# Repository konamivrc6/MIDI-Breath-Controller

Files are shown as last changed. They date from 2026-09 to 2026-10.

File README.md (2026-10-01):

# LnWS Breath Controller

吹气式 MIDI 呼吸控制器。MPX5010DP 气压传感器 + Pro Micro，把吹气压力映射成 MIDI CC#2 发给宿主。

- 开机自动零点校准
- 两种力度曲线（线性 / 平方根），由拨动开关切换
- TM1637 四位数码管实时显示当前 CC 值
- 主循环全程非阻塞

## 硬件

| 部件 | 型号 | 备注 |
|---|---|---|
| 主控 | Pro Micro (ATmega32U4, 5V / 16 MHz) | 2×12 排针插座 |
| 压力传感器 | MPX5010DP | 6 脚单排 SIP，量程 10 kPa |
| 显示 | TM1637 四位数码管 | 4 脚，2.54mm 间距 |
| 开关 | 3 脚拨动开关 | 2.0mm 间距 |
| 消抖电容 | 3 × 1µF 0805 MLCC | 并联，接开关公共端与 GND 之间 |
| 上拉 | 4.7k 0805 | 开关输入，保证触点湿电流 |
| 去耦电容 | 直插 1 枚 | 传感器旁电源去耦 |
| 气管 | 硅胶软管 | 内径 4mm / 外径 6mm |

PCB 尺寸 60 × 50 mm 双面板，4 个 3.2mm 安装孔。
设计文件 `PCB/LnWS Breath Controller.eprj2`（EasyEDA Pro），现行 Gerber 为 **`2026-10-01`**。

该版相对 06-07 首版的主要变化：布线由纯走线改为大面积铺铜；开关消抖电容由直插 100nF 换成 3 颗并联的 1µF 0805 MLCC；新增 4.7k 湿电流上拉。

### 引脚对照表

下表由 Gerber 铜箔层走线逆向得出，与固件里的定义一致。

| 信号 | Pro Micro 引脚 | 说明 |
|---|---|---|
| 传感器 Vout | **A0**（18 / PF7） | 模拟输入 |
| 传感器 GND | GND | |
| 传感器 Vs | VCC（5V） | |
| 数码管 CLK | **2** | |
| 数码管 DIO | **3** | |
| 拨动开关 | **4** | 接开关公共端；另一侧接地，靠 `INPUT_PULLUP` |
| 数码管 VCC | VCC（5V） | |
| 数码管 GND | GND | |

### 开关消抖的设计依据

开关公共端接 **4.7k 上拉**，并 **3 颗 1µF 0805 MLCC 并联到 GND**，构成 RC 消抖。固件里**不做软件消抖**，全部靠这段硬件完成。

两个参数都是被约束推出来的，**不要随手改其中一个**：

**上拉为什么是 4.7k —— 湿电流（wetting current）。**
机械开关的触点会形成氧化膜，电流太小就击不穿，接触电阻变得不稳定。镍/银镀层要求 **≥1mA**。触点闭合时电流 = 5V / R，所以 **R ≤ 5k**。取 4.7k → 1.06mA，是在满足湿电流的前提下能取的最大阻值。
（注意：Pro Micro 内部上拉是 20~50k，也就是 0.1~0.25mA —— 经典「内部上拉 + 100nF」的做法本来就跑在湿电流以下。）

**电容为什么是 3 颗 —— DC bias。**
MLCC 在直流偏压下容值会衰减，且衰减按**每颗**计算，并联不会改善比例。X7R 0805 在 5V 偏压下的典型衰减：25V 耐压约 25%，16V 约 35~45%，X5R 更差。所以不能按标称值算，要按**有效值**算：

| 规格 | 颗数 | 标称 | 有效值 | τ = R_total × C_eff |
|---|---|---|---|---|
| 1µF 0805 25V X7R | 2 | 2.0 µF | 1.5 µF | 5.7 ~ 6.4 ms |
| 1µF 0805 16V X7R | 3 | 3.0 µF | 1.65 ~ 1.95 µF | 6.9 ~ 7.7 ms |
| 1µF 0805 16V X5R | 3 | 3.0 µF | 1.35 ~ 1.65 µF | 5.7 ~ 6.4 ms |

本板用 3 颗，对上述任一规格都留有余量（小型滑动开关典型抖动 1~5ms）。反过来，只放 1 颗在衰减超过 30% 时 τ 就会掉到 3ms 以下，压不住抖动。

**并联上拉的影响 —— 反而让 τ 变确定了。**
固件保留 `INPUT_PULLUP`，内部上拉（20~50 kΩ）与外部 4.7k 并联，总阻为 **3.81 ~ 4.30 kΩ**：

| R_pu | R_total | 湿电流 |
|---|---|---|
| 20 kΩ | 3.81 kΩ | 1.31 mA |
| 30 kΩ | 4.06 kΩ | 1.23 mA |
| 50 kΩ | 4.30 kΩ | 1.16 mA |

因为 4.7k 远小于内部上拉，**它主导了并联结果** —— 内部那个 2.5 倍的离散被压缩到 1.13 倍，τ 实际上是确定的。副带好处是湿电流从 1.06mA 抬到 1.16~1.31mA。
保留内部上拉还有兜底作用：万一外部 4.7k 虚焊，τ 会变长到 30~75ms，模式切换变迟钝但功能不丢。

> ⚠️ 改动这里的 R 或 C 之前，务必重算**湿电流**和 **DC bias 后的有效容值** —— 这两者是互相拉扯的（湿电流要求 R 小，消抖要求 R×C 大），只调一个必然破坏另一个。

### MPX5010DP 接线

| 脚 | 名称 | 板上接到 |
|---|---|---|
| 1 | Vout | A0 |
| 2 | GND | GND |
| 3 | Vs | 5V |
| 4 | V1 | 悬空 |
| 5 | V2 | 悬空 |
| 6 | VEX | 悬空 |

> ✅ **4 / 5 / 6 脚全部悬空，符合数据手册。** V1、V2、VEX 是工厂激光修调脚，NXP 明确要求悬空不接。
> 早期版本曾把 4 脚接到 5V、5 脚接到 GND（偏离数据手册），现行版本已修正。

> ⚠️ **不要直接焊接传感器。** 引脚粗、散热快，烙铁停留稍久就会烫坏——本项目已经因此报废过一块。建议在板上装 **6 脚圆孔母座**，传感器插上去，既不烫坏也方便更换。

> ⚠️ **1 脚是缺口标记的那一端。** 插反会把 Vout 直接接到 5V 上。

## 开发环境

### 1. 安装依赖库

把 `libraries/` 下的 **`MIDIUSB`** 和 **`TM1637`** 拷贝到：

```
%USERPROFILE%\Documents\Arduino\libraries\
```

### 2. 安装开发板定义

这个板子定义不在官方 Arduino AVR 核里，需要手动追加。

把 `boards_add in the end.txt` 的内容**追加到文件末尾**：

```
%LOCALAPPDATA%\Arduino15\packages\arduino\hardware\avr\<版本>\boards.txt
```

追加后重启 Arduino IDE，开发板菜单里会出现 **"LnWS Breath Controller"**。

> ⚠️ **Arduino AVR 核一升级，这个文件就会被重置**，需要重新追加。

定义本身只是「SparkFun Pro Micro 换了个 USB 设备名」，其中有两处是踩过坑才改对的：

- **`build.variant=leonardo`** —— 官方核里没有 `promicro` variant。Leonardo 与 Pro Micro 的引脚映射逐位相同（已核对两张 `PROGMEM` 表的 `digital_pin_to_port_PGM` / `digital_pin_to_bit_mask_PGM`），所以直接复用。
- **`upload.tool.serial` / `upload.tool.default=avrdude`** —— 这两行原本没有，IDE 2.x 上传时会报 `Property 'upload.tool.serial' is undefined`。

> ⚠️ **不要点 "Burn Bootloader / 烧录引导程序"。** 定义里引用的 `Caterina-promicro16.hex` 在官方核中不存在，会报错。Pro Micro 出厂自带引导程序，正常上传（Upload）不受影响。

上传后设备会显示为 **`SparkFun LnWS Breath Controller`** —— VID 是 `0x1b4f`，而 Arduino 核里对这个 VID 硬编码了厂商名 "SparkFun"（见 `cores/arduino/USBCore.cpp`）。

## 标定

固件里的 `FULL_RAW` 是「净 ADC 计数 → 满量程」的换算基准，**必须用实际传感器实测确定**，不能沿用别的传感器的数据。代码里留了 TODO。

1. 烧录 `testSensorMPX5010DP/testSensorMPX5010DP.ino`
2. 打开串口监视器（115200）
3. **传感器不通气** → 记下 Raw 值，即零点 `zero`
4. **用平时最大的力度吹** → 记下 Raw 值，即峰值 `peak`
5. 把 `FULL_RAW = peak - zero` 填回 `LnWSBreathController.ino`

参考：按数据手册 `Vout = Vs*(0.09*P + 0.04)`，5V 供电下 0→10 kPa 对应净读数约 **921**。若实测明显偏小，说明最大吹气压力不到 10 kPa——那就直接用实测值，等于把「你吹得动的最大值」当作满量程，0~127 整个范围都用得上，分辨率最好。

## 目录

```
Code/LnWSBreathController/   固件（Arduino sketch）
PCB/                         EasyEDA Pro 工程 + Gerber
Casing/                      外壳（Blender 源文件 + STL）
libraries/                   依赖库（MIDIUSB、TM1637）
testSensorMPX5010DP/         传感器单独测试用 sketch
3D_PCB1_2026-06-07.step      PCB 3D 模型（供外壳建模参照）
```

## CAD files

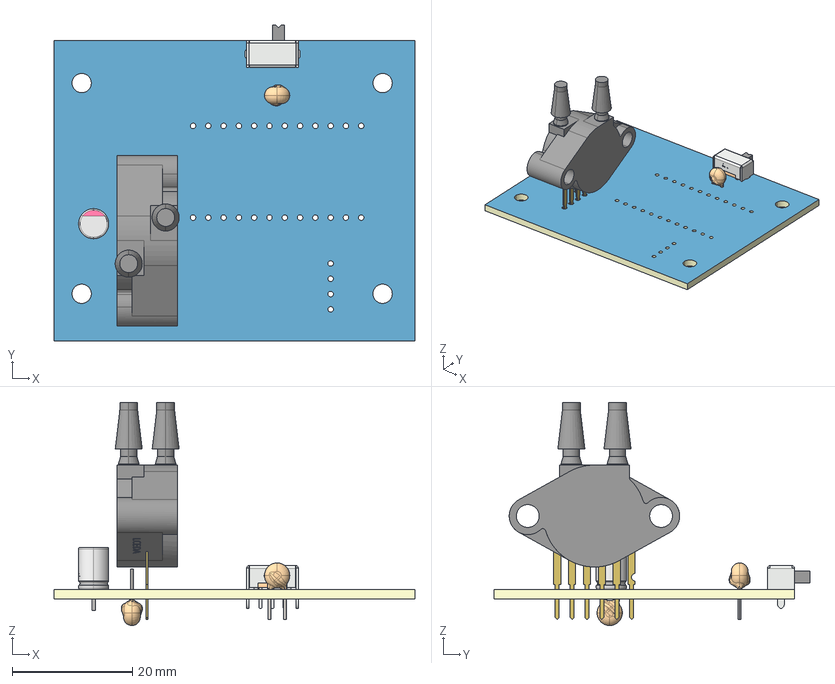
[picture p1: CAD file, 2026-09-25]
3D_PCB1_2026-06-07.step
60.0 x 52.6 x 37.1 mm
Board~5Xmx
TopCopper~5Xmx
BottomCopper~5Xmx
TopSilkscreen~5Xmx
BottomSilkscreen~5Xmx
TopFpcStiffener~5Xmx
BottomFpcStiffener~5Xmx
SW-TH_SK12D07VG4~SW-TH_L8.7-W4.4-H4.0-P2.0~5Xmx
SENSOR-TH_MPX5050DP~SENSOR-TH_MPX5050DP~5Xmx
CAP-TH_BD5.0-P2.00-D0.6-FD~CAP-TH_BD5.0-P2.00-D0.6-FD~5Xmx
CAP-TH_L4.2-W3.5-P2.54-D0.5~CAP-TH_L4.2-W3.5-P2.54-D0.5~5Xmx x 2

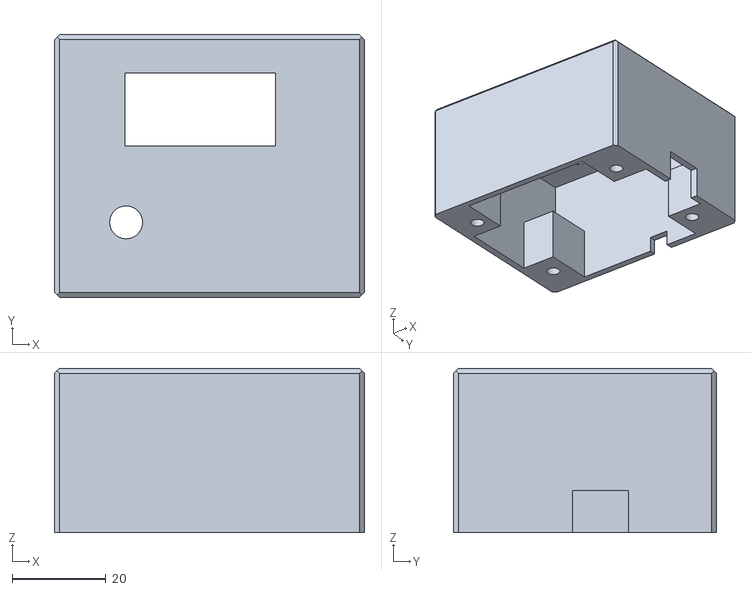
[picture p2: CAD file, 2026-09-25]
Casing/外壳上.stl
66.0 x 56.0 x 35.0

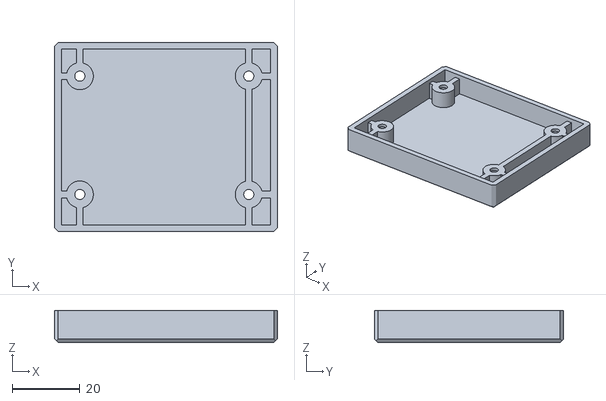
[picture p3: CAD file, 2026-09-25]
Casing/外壳下_fixed.stl
66.0 x 56.0 x 9.50

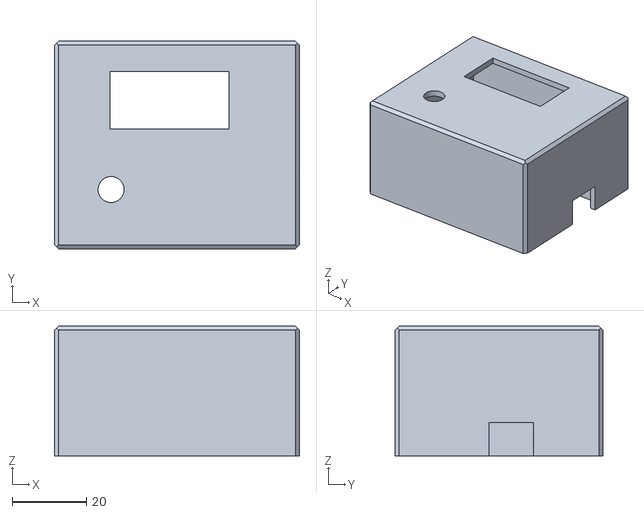
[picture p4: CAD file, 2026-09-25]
Casing/外壳上_fixed.stl
66.0 x 56.0 x 35.0

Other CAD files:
3D_PCB1_2026-06-07/3D_PCB1_2026-06-07.obj
Casing/外壳下.stl
Casing/Casing.blend
Casing/外壳上.blend
Casing/外壳下.blend

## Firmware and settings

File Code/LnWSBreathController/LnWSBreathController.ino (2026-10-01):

/*
  呼吸控制器 - Pro Micro
  功能：
    - 读取 MPX5010DP 压力传感器 (A0)
    - 自动零点校准 (开机无气流)
    - 两种力度曲线 (线性 / 自定义)，由拨动开关 (引脚4) 切换
    - TM1637 四位数码管显示当前 CC 值 (引脚2,3)
    - 通过 USB-MIDI 发送 CC#2 (呼吸控制)
    - 主循环全程非阻塞；开关消抖由硬件 RC (100nF) 完成，软件只做边沿检测
*/

#include <MIDIUSB.h>
#include <TM1637Display.h>

// ==================== 引脚定义 ====================
#define PRESSURE_PIN    A0       // 压力传感器模拟输入
#define SWITCH_PIN      4        // 曲线切换开关 (INPUT_PULLUP)
#define CLK_PIN         2        // TM1637 时钟
#define DIO_PIN         3        // TM1637 数据

// ==================== 传感器参数 ====================
const float FULL_PRESSURE_KPA = 10.0;   // 传感器标称量程 10 kPa

// ★ 满量程标定值 —— 这项必须用实际的传感器实测，不要沿用上一块件的数据 ★
//
// 含义：净 ADC 计数 (已减零点) 达到多少时，认为压力到了 10 kPa / CC 到 127。
// 测法：烧录 testSensorMPX5010DP.ino，开串口监视器 (115200)
//   1. 传感器不通气          -> 记下 Raw，即零点 zero
//   2. 用平时最大的力度吹    -> 记下 Raw，即峰值 peak
//   3. FULL_RAW = peak - zero
//
// 参考：按数据手册 Vout = Vs*(0.09*P + 0.04)，5V 供电下 0→10 kPa
//       对应净读数约 921。若实测明显偏小，说明你最大吹气压力不到
//       10 kPa —— 那就直接用实测值，等于把「你吹得动的最大值」当作
//       满量程，这样 0~127 的整个范围都用得上，分辨率最好。
//
// 注意：getNetPressureKpa() 返回的 kPa 只有在 FULL_RAW 标定正确时
//       才有物理意义，否则它只是个线性刻度。
const int FULL_RAW = 500;               // TODO: 待新传感器实测后替换

// ==================== MIDI 设置 ====================
const byte MIDI_CHANNEL = 0;     // MIDI 通道 1 (0-based)
const byte CC_NUMBER = 2;       // 呼吸控制 CC
const unsigned long SEND_INTERVAL = 15;   // 发送最小间隔 (ms)

// ==================== 滤波与死区 ====================
const int AVG_SAMPLES = 8;      // 压力采样平均次数
const float DEAD_ZONE_KPA = 0.02;  // 死区压力 (kPa)，低于此值 CC=0
const int CALIB_SAMPLES = 100;     // 零点校准采样次数

// ==================== 显示 ====================
const unsigned long DISP_REFRESH = 50;   // 数码管刷新间隔 (ms)

// ==================== 曲线模式 ====================
enum CurveMode {
  LINEAR,
  CUSTOM
};

// ==================== 全局变量 ====================
TM1637Display display(CLK_PIN, DIO_PIN);   // 数码管对象

float zeroPressureRaw = 0;      // 零点 ADC 平均值 (原始读数)
CurveMode currentMode = LINEAR; // 当前曲线模式
byte lastCCValue = 255;        // 上次发送的 CC 值 (初始化为无效值)
unsigned long lastSendTime = 0;
unsigned long lastDisplayTime = 0;
bool lastSwitchState = HIGH;   // 上一次开关状态 (未按下为HIGH)

// ==================== 函数声明 ====================
void calibrateZero();
float readPressureRaw();
float getNetPressureKpa();
byte pressureToCC(float kPa, CurveMode mode);
void sendMidiCC(byte value);
void updateDisplay(byte value);
void checkSwitch();

// ==================== 初始化 ====================
void setup() {
  // 调试串口 (可选，如需查看压力值可取消注释)
  Serial.begin(115200);

  // 初始化引脚
  pinMode(SWITCH_PIN, INPUT_PULLUP);
  pinMode(PRESSURE_PIN, INPUT);

  // 初始化 TM1637
  display.setBrightness(7);  // 最大亮度
  display.clear();

  // 开机零点校准 (请确保此时传感器无气流)
  calibrateZero();

  // 读取当前开关状态，设置初始曲线模式
  lastSwitchState = digitalRead(SWITCH_PIN);
  currentMode = (lastSwitchState == HIGH) ? LINEAR : CUSTOM;
  // 启动时强制发送一次 CC=0
  sendMidiCC(0);
  lastCCValue = 0;
  updateDisplay(0);

  // Serial.println("Ready");
}

void loop() {
  // 1. 检查拨动开关是否变化 (边缘检测)
  checkSwitch();

  // 2. 获取当前净压力
  float netKpa = getNetPressureKpa();
  // 死区处理
  if (netKpa < DEAD_ZONE_KPA) netKpa = 0.0;

  // 3. 计算 CC 值
  byte cc = pressureToCC(netKpa, currentMode);

  // 4. 条件发送 MIDI
  if (cc != lastCCValue && (millis() - lastSendTime >= SEND_INTERVAL)) {
    sendMidiCC(cc);
    lastCCValue = cc;
    lastSendTime = millis();
  }

  // 5. 更新数码管 (非阻塞)
  if (millis() - lastDisplayTime >= DISP_REFRESH) {
    updateDisplay(cc);
    lastDisplayTime = millis();
  }

  // 6. 处理 USB-MIDI 主机接收 (必须周期性调用，避免数据堆积)
  MidiUSB.flush();
}

// ==================== 零点校准 ====================
void calibrateZero() {
  unsigned long sum = 0;
  for (int i = 0; i < CALIB_SAMPLES; i++) {
    sum += analogRead(PRESSURE_PIN);
    delay(2); // 短暂暂停，允许 ADC 稳定
  }
  zeroPressureRaw = (float)sum / CALIB_SAMPLES;
  // 调试输出零点 (保留注释方便测试)
  // Serial.print("Zero raw: "); Serial.println(zeroPressureRaw);
}

// ==================== 压力读取 ====================
float readPressureRaw() {
  // 多次采样平均滤波
  unsigned long sum = 0;
  for (int i = 0; i < AVG_SAMPLES; i++) {
    sum += analogRead(PRESSURE_PIN);
    delayMicroseconds(50);
  }
  return (float)sum / AVG_SAMPLES;
}

// 计算净压力 (kPa)
float getNetPressureKpa() {
  float raw = readPressureRaw();
  float netRaw = raw - zeroPressureRaw;
  // 限制在 0 ~ FULL_RAW 之间，防止负值或超出
  if (netRaw < 0) netRaw = 0;
  if (netRaw > FULL_RAW) netRaw = FULL_RAW;
  // 线性映射到 kPa：0 -> 0, FULL_RAW -> FULL_PRESSURE_KPA
  float kpa = (netRaw / FULL_RAW) * FULL_PRESSURE_KPA;
  return kpa;
}

// ==================== 曲线映射 ====================
byte pressureToCC(float kPa, CurveMode mode) {
  if (kPa <= 0.0) return 0;
  // 归一化压力 (0..1)
  float norm = kPa / FULL_PRESSURE_KPA;
  if (norm > 1.0) norm = 1.0;

  byte cc;
  switch (mode) {
    case LINEAR:
      // 线性映射: 0..127
      cc = (byte)(norm * 127.0 + 0.5);
      break;
    case CUSTOM:
      // 自定义曲线: 平方根 (初段灵敏，后段平缓)
      // 也防止陡增造成难以精细控制
      cc = (byte)(sqrt(norm) * 127.0 + 0.5);
      break;
  }
  return cc;
}

// ==================== MIDI 发送 ====================
void sendMidiCC(byte value) {
  // 构造 Control Change 消息
  midiEventPacket_t event = {
    (byte)0x0B,           // Cable 0 + 3 bytes of message
    (byte)(0xB0 | MIDI_CHANNEL), // Control Change on channel
    CC_NUMBER,            // CC 编号
    value                 // CC 值
  };
  MidiUSB.sendMIDI(event);
  // 立即 flush 以确保发出
  MidiUSB.flush();
  // 调试输出 (可选)
  // Serial.print("CC: "); Serial.println(value);
}

// ==================== 数码管更新 ====================
void updateDisplay(byte value) {
  // 显示 4 位数，右对齐，不填充前导零
  // length 必须给 4：库内部是 setSegments(digits, length, pos)，
  // 只写 length 个位置。给 3 的话第 4 位永远不被写，屏幕上会空一格。
  display.showNumberDec(value, false, 4, 0);
}

// ==================== 开关检测 ====================
// 硬件侧已经在开关两端并了 100nF 到 GND (PCB 上的 C1)，配合引脚内部
// 上拉形成了 RC 消抖，所以这里只做边沿检测，不加任何延时或重复确认
// —— 之前那句 delay(30) 是多余的，而且会阻塞主循环。
void checkSwitch() {
  bool currentState = digitalRead(SWITCH_PIN);
  if (currentState == lastSwitchState) return;

  lastSwitchState = currentState;
  // 更新曲线模式：高电平(未按下) -> 线性；低电平(按下) -> 自定义
  currentMode = (currentState == HIGH) ? LINEAR : CUSTOM;

  // 切换模式时，强制发送当前压力对应的新 CC 值，避免宿主残留旧值
  float netKpa = getNetPressureKpa();
  if (netKpa < DEAD_ZONE_KPA) netKpa = 0.0;
  byte cc = pressureToCC(netKpa, currentMode);
  sendMidiCC(cc);
  lastCCValue = cc;
  updateDisplay(cc);
  // 重置发送计时器，防止后续正常发送被间隔限制
  lastSendTime = millis();
}

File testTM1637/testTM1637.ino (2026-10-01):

/*
 * TM1637 四位数码管测试
 *
 * 用途：单独验证数码管本身和它的接线，不涉及压力传感器和开关。
 * 四个测试项循环执行，全程在串口打印当前在测什么（波特率 115200）。
 *
 * 接线（与主板一致，见 README 的引脚对照表）
 *   CLK -> D2
 *   DIO -> D3
 *   VCC -> 5V
 *   GND -> GND
 *
 * 故障对照
 *   完全黑屏            -> 先查 VCC / GND；再确认 CLK 和 DIO 都接上了
 *   只亮一部分位/段     -> 数码管模块本身损坏
 *   乱码、闪烁、跳字    -> CLK 与 DIO 接反（最常见的一种）
 *   亮度忽明忽暗        -> 供电不足，给模块 VCC 就近加 100nF 去耦
 *   串口一片空白        -> 波特率不是 115200，或者 COM 口选错
 */

#include <TM1637Display.h>

// ==================== 接线 ====================
#define CLK_PIN   2
#define DIO_PIN   3

// ==================== 节奏 ====================
const unsigned long HOLD_MS = 1500;   // 每项测试停留时间
const unsigned long STEP_MS = 300;    // 单项内每步的间隔

// ==================== 全局 ====================
TM1637Display display(CLK_PIN, DIO_PIN);

// 四位全段点亮用的段码（0xff = 该位所有段都亮）
const uint8_t ALL_ON[4] = { 0xff, 0xff, 0xff, 0xff };

// ==================== 初始化 ====================
void setup() {
  Serial.begin(115200);
  // Pro Micro 的串口是 USB CDC。等终端连上来，但最多等 3 秒，
  // 否则没打开串口监视器时会永远卡在这里。
  while (!Serial && millis() < 3000) { }

  Serial.println(F("=== TM1637 数码管测试 ==="));
  Serial.print(F("CLK = D")); Serial.print(CLK_PIN);
  Serial.print(F("    DIO = D")); Serial.println(DIO_PIN);
  Serial.println();

  display.setBrightness(7);
  display.clear();
  delay(200);
}

// ==================== 主循环 ====================
void loop() {
  testAllSegments();
  testBrightness();
  testCountUp();
  testFirmwareStyle();

  Serial.println(F("--- 一轮结束，从头再来 ---"));
  Serial.println();
}

// ==================== 1. 全段点亮 ====================
// 确认模块没坏、每一位都能亮，顺便确认位序
void testAllSegments() {
  Serial.println(F("[1/4] 全段点亮"));
  display.setBrightness(7);

  display.setSegments(ALL_ON, 4, 0);
  Serial.println(F("      四位全亮 8.8.8.8"));
  Serial.println(F("      如果有某一段不亮，记下是第几位、哪一段"));
  delay(HOLD_MS);

  // 逐位单独点亮：从左到右依次是第 1、2、3、4 位
  for (uint8_t pos = 0; pos < 4; pos++) {
    uint8_t one[4] = { 0, 0, 0, 0 };
    one[pos] = 0xff;
    display.setSegments(one, 4, 0);
    Serial.print(F("      只亮第 ")); Serial.print(pos + 1); Serial.println(F(" 位（从左数）"));
    delay(STEP_MS * 2);
  }

  display.clear();
  delay(200);
}

// ==================== 2. 亮度扫描 ====================
// 0 最暗、7 最亮。TM1637 的亮度 0 不是关屏，是 1/16 占空比，仍然可见
void testBrightness() {
  Serial.println(F("[2/4] 亮度 0 → 7（0 最暗，7 最亮）"));
  display.showNumberDec(8888, false, 4, 0);

  for (uint8_t b = 0; b <= 7; b++) {
    display.setBrightness(b);
    Serial.print(F("      亮度 ")); Serial.println(b);
    delay(STEP_MS * 2);
  }

  display.setBrightness(7);
  display.clear();
  delay(200);
}

// ==================== 3. 计数 0 → 127 ====================
// 127 是 MIDI CC 的最大值，正好覆盖实际会用到的整个范围
void testCountUp() {
  Serial.println(F("[3/4] 计数 0 → 127（MIDI CC 的值域）"));
  display.setBrightness(7);

  for (int v = 0; v <= 127; v++) {
    display.showNumberDec(v, false, 4, 0);
    delay(15);
  }

  delay(HOLD_MS);
  display.clear();
  delay(200);
}

// ==================== 4. 两种调用方式对比 ====================
// LnWSBreathController.ino 里用的是 length=3、pos=0，
// 也就是只写前三位，最右边那一位从头到尾没被写过。
// 这里把两种写法并排演示一下，差别一眼可见。
void testFirmwareStyle() {
  const int demo = 42;

  Serial.println(F("[4/4] 对比两种调用方式，看最右边那一位"));

  // --- 主固件当前用法 ---
  Serial.println(F("      (a) showNumberDec(42, false, 3, 0)  <- 固件现在的写法"));
  Serial.println(F("          只写前三位，第 4 位保持空白"));
  display.clear();
  display.setBrightness(7);
  display.showNumberDec(demo, false, 3, 0);
  delay(HOLD_MS * 2);

  // --- 四位右对齐 ---
  Serial.println(F("      (b) showNumberDec(42, false, 4, 0)  <- 占满四位、右对齐"));
  display.clear();
  display.showNumberDec(demo, false, 4, 0);
  delay(HOLD_MS * 2);

  // --- 边界值也过一眼 ---
  display.clear();
  Serial.println(F("      (b) 在边界值 0 / 127 上的表现"));
  display.showNumberDec(0, false, 4, 0);
  delay(STEP_MS * 3);
  display.showNumberDec(127, false, 4, 0);
  delay(HOLD_MS);

  display.clear();
  delay(200);
}

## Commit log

2026-09-25 归档项目成果，清理固件，统一换行为 LF
    ## 归档
    此前仓库只有首版 Gerber 和传感器测试 sketch，实际成果几乎全未入库。
    本次纳入版本控制：
    - Code/ 固件 (Arduino sketch)
    - Casing/ 外壳 Blender 源文件 + STL
    - libraries/ 依赖库 MIDIUSB、TM1637
    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
    [3D_PCB1_2026-06-07.obj, 3D_PCB1_2026-06-07.step, Casing.blend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]
2026-10-01 PCB 改版：改为铺铜，电容选型调整，增加 4.7k 上拉
    - 布线由纯走线改为大面积铺铜（顶层 20 块 / 底层 41 块铜皮）
    - 两个电容引脚间距由 2.54mm 改为 5.0mm（去耦电容与开关消抖电容各一）
    - 新增一枚 SMD 4.7k 上拉电阻（新增顶层钢网层）
    - Pro Micro、数码管、拨动开关、传感器 U1 的封装位置与孔径均未变
    - Gerber：新增 2026-10-01，删除 06-07 与 09-12（旧版仍存于 c53e53d）
    - 更新 EasyEDA 工程文件
2026-10-01 PCB 换用 3 颗 1µF 0805 消抖电容，README 补上选型依据
    PCB：
    - 删除直插消抖电容（5.0mm 间距）
    - 新增 3 颗 1µF 0805 MLCC 并联，另加 2 个接地过孔
    - MPX5010DP 的 4 脚（V1）、5 脚（V2）改为悬空，符合数据手册要求
    - 4.7k 湿电流上拉保持不变
    - 更新 2026-10-01 Gerber 与 EasyEDA 工程文件
    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
2026-10-01 新增 TM1637 数码管测试 sketch，修正主固件少写一位数码管
    testTM1637/testTM1637.ino（新增）
    - 四个测试项循环执行：
    全段点亮 8.8.8.8 + 逐位单独点亮（查位序和坏段）
    亮度 0 → 7（TM1637 的亮度 0 是 1/16 占空比，不是关屏）
    计数 0 → 127（覆盖 MIDI CC 值域）
    两种 showNumberDec 调用方式并排对比
    - 文件头附接线说明与故障对照表（黑屏 / 乱码 / 亮度不稳 / 串口无输出）
    LnWSBreathController.ino
    - updateDisplay() 的 showNumberDec 由 length=3 改为 length=4
    库实现是 setSegments(digits, length, pos)，只写 length 个位置。
    length=3、pos=0 时第 4 位从头到尾不会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
    [LnWSBreathController.ino, testTM1637.ino]
2026-10-01 PCB 为数码管加去耦电容，调换 VCC/GND 接线
    - 新增 100nF 直插电容（5.0mm 间距 / 0.8mm 孔）于数码管排针旁
    - 新增 1µF 0805 MLCC 于数码管排针旁
    两者并联在排针的 VCC 与 GND 之间，抑制 TM1637 扫描驱动的脉冲电流
    流经共享电源/地时对压力传感器读数造成的干扰
    - 调换数码管 VCC / GND 的接线
    - .gitignore 忽略 EasyEDA 自动生成的 *_backup/ 目录
    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
